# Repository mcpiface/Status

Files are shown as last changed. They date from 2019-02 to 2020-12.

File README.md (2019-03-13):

# McPiFace Status Board

Rack Mountable Raspberry Pi Status Board.

A status board in the McPiFace series, intended to fit the 19" rack frame as a quick status indicator.

Based on the Status Board Hat: https://thepihut.com/products/status-board-pro

## Versions

Version 2: Uses MCP23017 with The Pi's I2C. Uses the McPi I2C 6 Pin JST SH connection
https://github.com/mcpiface/Status/tree/master/V2

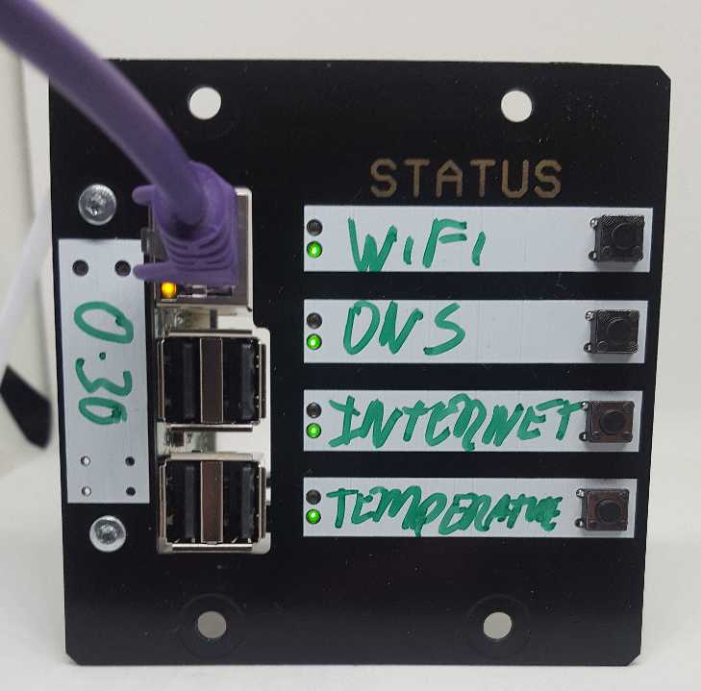
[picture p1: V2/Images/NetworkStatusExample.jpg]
V2 Status Board


Version 1: Needs 3x connectors and 15 GPIO on Pi. Uses Pi GPIOs - similar (different pins) to the Status Board Hat.
https://github.com/mcpiface/Status/tree/master/V1

## Sled

To mount the raspberry Pi a 3D printable sled is available:

https://www.thingiverse.com/thing:3488157

## Rack Mount Frame

DAP Audio 2 HE Rackblende f. Modulsystem 10 Segmente MP-1 from Music Store.

* UK: https://www.dv247.com/en_GB/GBP/DAP-Audio-2-HE-Rackblende-f-Modulsystem-10-Segmente-MP-1/art-PAH0017160-000

* Germany: https://www.musicstore.de/en_US/USD/DAP-Audio-2-HE-Rackblende-f-Modulsystem-10-Segmente-MP-1/art-PAH0017160-000

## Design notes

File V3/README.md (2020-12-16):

# McPiFace Status Board - Version 2

Rack Mountable Raspberry Pi Status Board.

Features 4x status indicators with red/green LEDs and optional buttons.

A status board in the McPiFace series, intended to fit the 19" rack frame as a quick status indicator.

This version uses the MCP23017 with The Pi's I2C. 

The connection uses the McPi I2C 6 Pin JST SH connection (1:1 connection with the first 6 pins of the Raspberry Pi second row of pins on the 40 pin header).

Status Board Usage

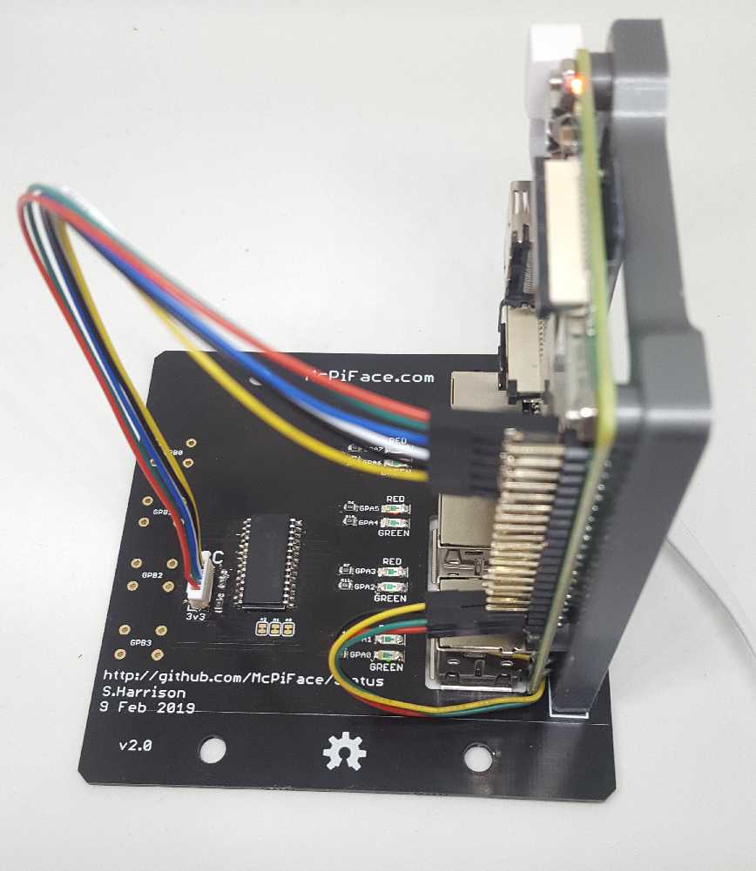
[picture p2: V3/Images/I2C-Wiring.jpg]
I2C Wiring


I2C Wiring 2

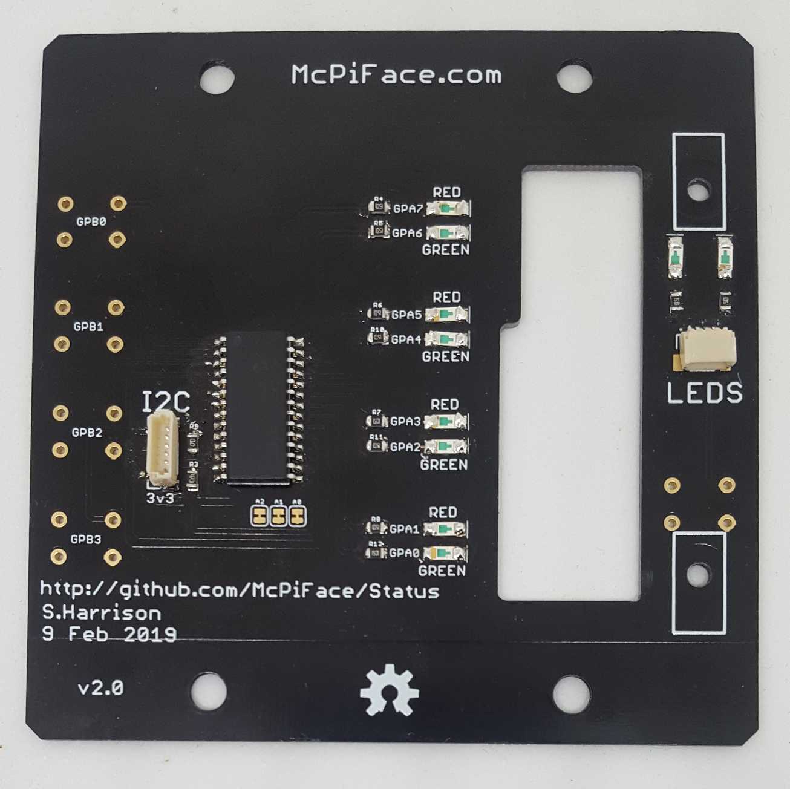
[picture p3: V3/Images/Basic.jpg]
Basic Layout


![Schematic] (Images/Schematic.png)

## Examples

See the examples folder for examples of use.

## Sled

To mount the raspberry Pi a 3D printable sled is available:

https://www.thingiverse.com/thing:3488157

## Rack Mount Frame

DAP Audio 2 HE Rackblende f. Modulsystem 10 Segmente MP-1 from Music Store.

* UK: https://www.dv247.com/en_GB/GBP/DAP-Audio-2-HE-Rackblende-f-Modulsystem-10-Segmente-MP-1/art-PAH0017160-000

* Germany: https://www.musicstore.de/en_US/USD/DAP-Audio-2-HE-Rackblende-f-Modulsystem-10-Segmente-MP-1/art-PAH0017160-000

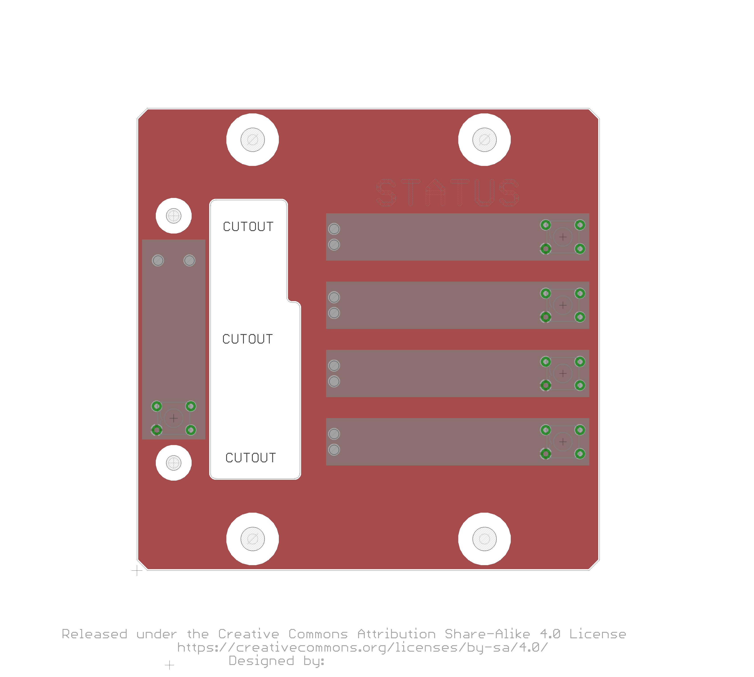
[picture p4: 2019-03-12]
V3/Images/PcbTopDesign.png

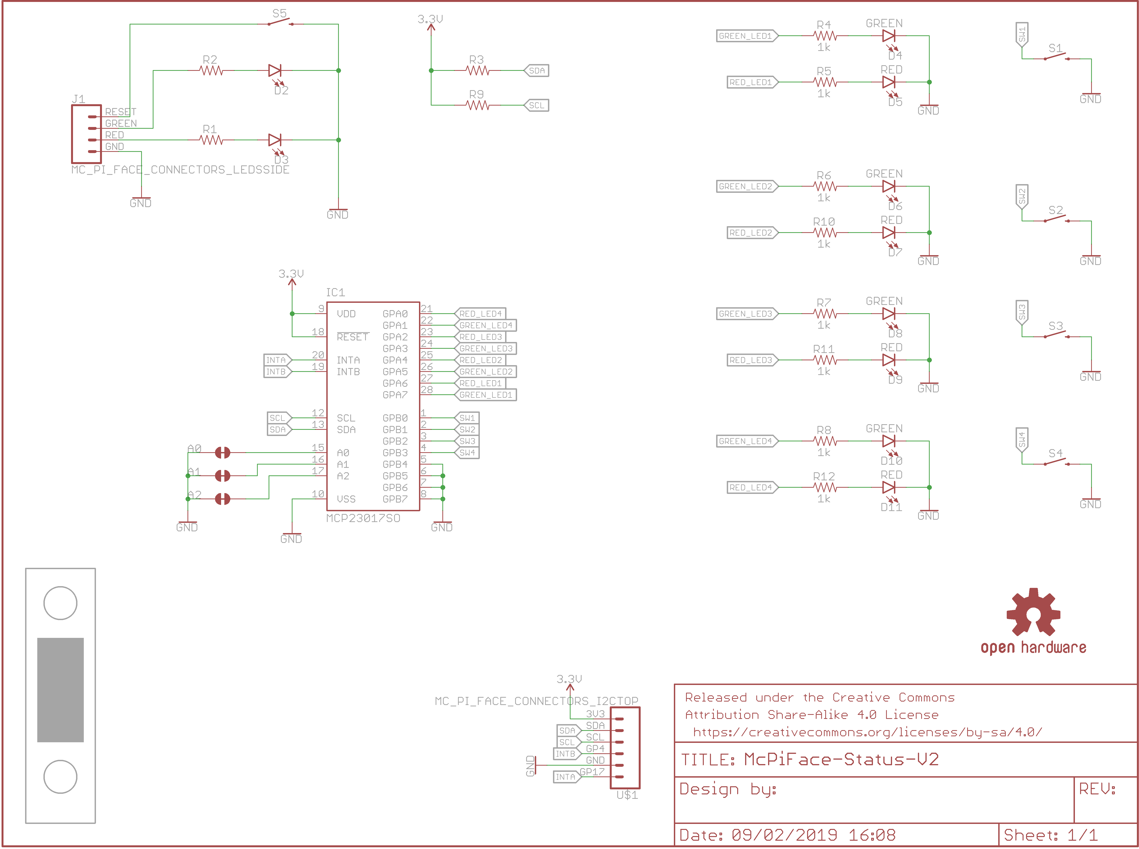
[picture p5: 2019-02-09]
V3/Images/Schematic.png

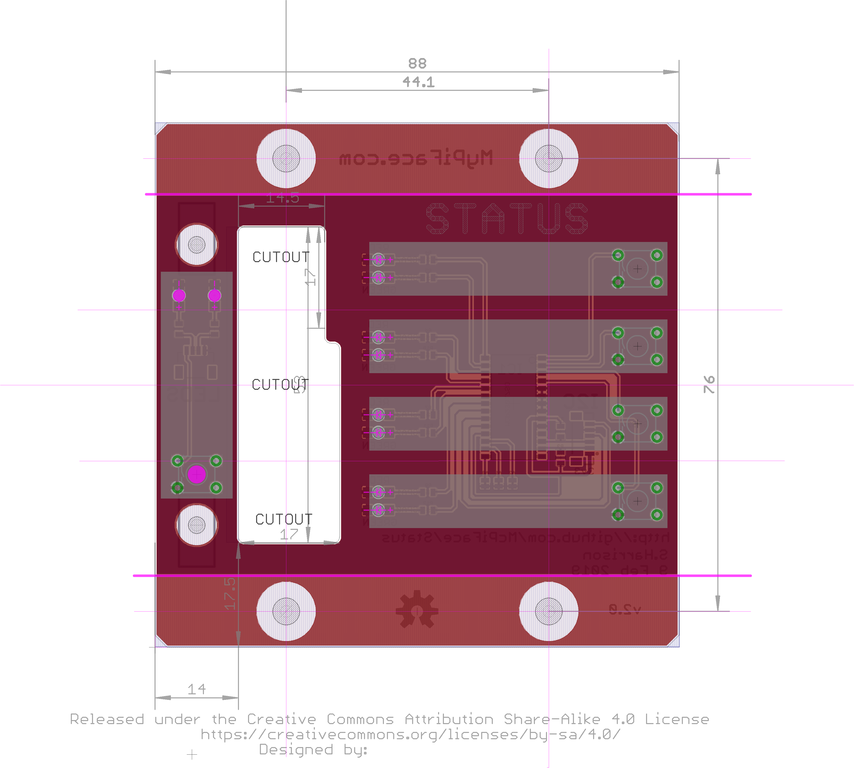
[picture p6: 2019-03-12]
V3/Images/PcbAllLayersDesign.png

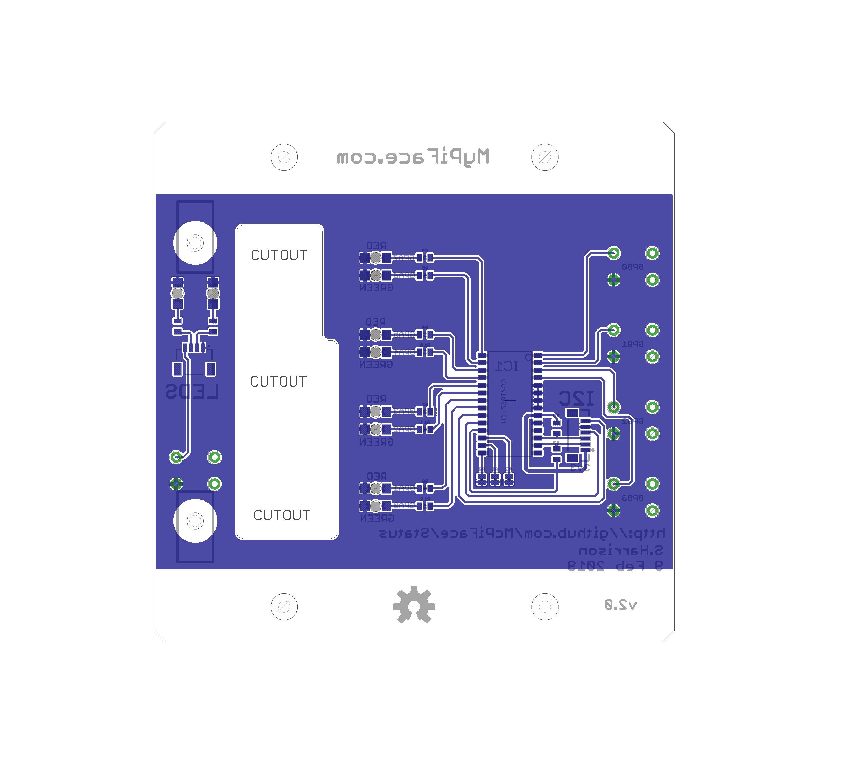
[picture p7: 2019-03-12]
V3/Images/PcbBottomDesign.png

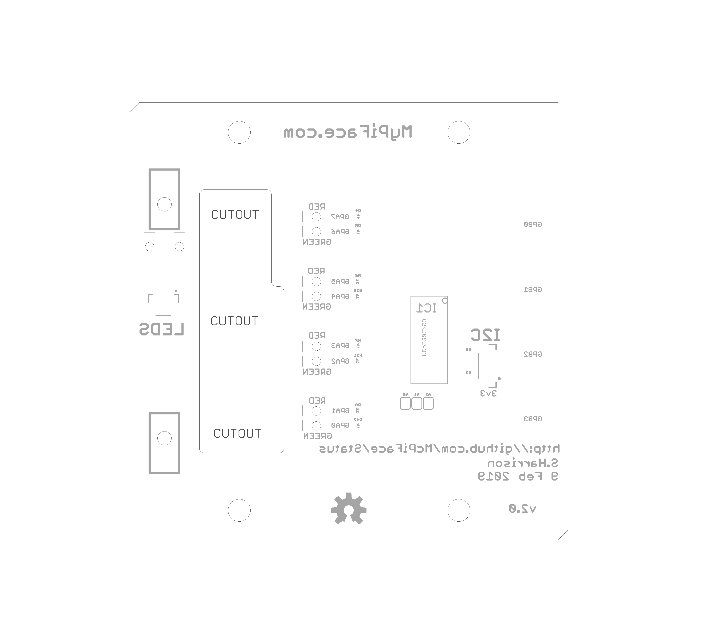
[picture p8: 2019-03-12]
V3/Images/PcbBottomSilkAndValues.png

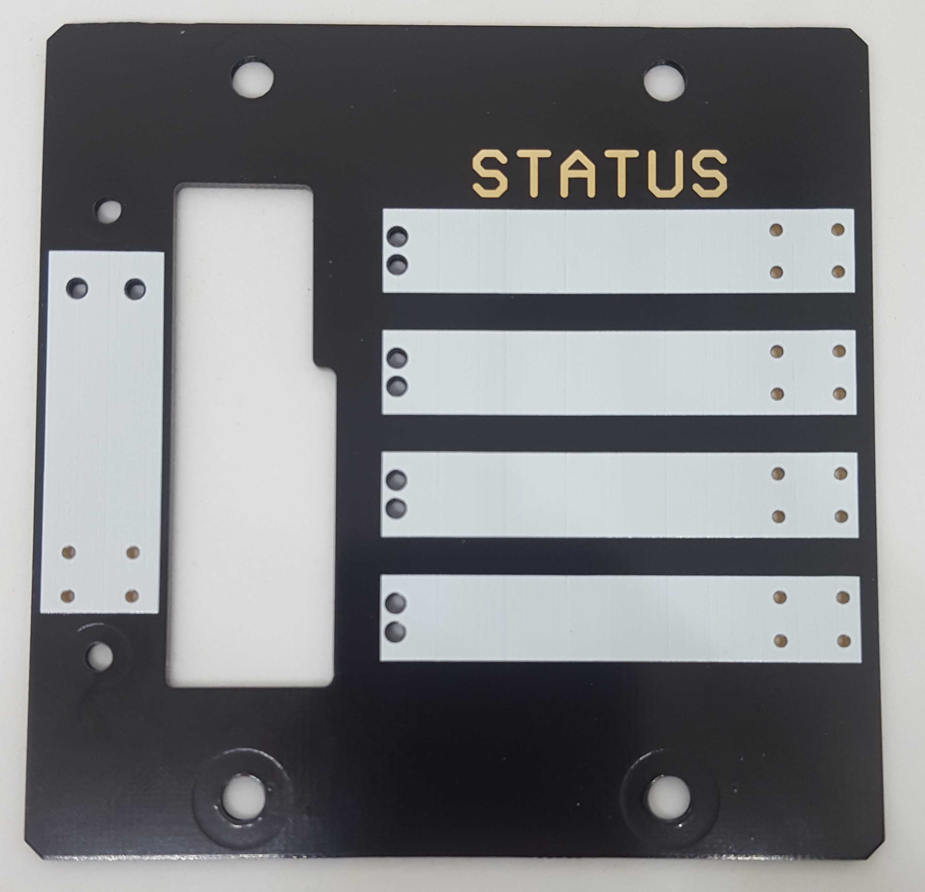
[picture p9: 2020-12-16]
V3/Images/PCBOnly.jpg

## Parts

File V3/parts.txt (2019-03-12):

Partlist

Exported from McPiFace-Status-V2.brd at 16/02/2019 17:04

EAGLE Version 7.4.0 Copyright (c) 1988-2015 CadSoft

Assembly variant: 

Part     Value                                                        Package                                Library            Position (mm)         Orientation

A0       JUMPER-SMT_2_NC_TRACE_SILK                                   SMT-JUMPER_2_NC_TRACE_SILK             SparkFun-Jumpers   (55.4 27.5)           MR90
A1       JUMPER-SMT_2_NC_TRACE_SILK                                   SMT-JUMPER_2_NC_TRACE_SILK             SparkFun-Jumpers   (57.7 27.5)           MR90
A2       JUMPER-SMT_2_NC_TRACE_SILK                                   SMT-JUMPER_2_NC_TRACE_SILK             SparkFun-Jumpers   (60 27.5)             MR90
D2                                                                    LED-1206-BOTTOM-2.0MM                  ThingySticks       (4 59)                MR90
D3                                                                    LED-1206-BOTTOM-2.0MM                  ThingySticks       (10 59)               MR90
D4       GREEN                                                        LED-1206-BOTTOM-2.0MM                  ThingySticks       (37.5 65)             MR0
D5       RED                                                          LED-1206-BOTTOM-2.0MM                  ThingySticks       (37.5 62)             MR0
D6       GREEN                                                        LED-1206-BOTTOM-2.0MM                  ThingySticks       (37.5 52)             MR0
D7       RED                                                          LED-1206-BOTTOM-2.0MM                  ThingySticks       (37.5 49)             MR0
D8       GREEN                                                        LED-1206-BOTTOM-2.0MM                  ThingySticks       (37.5 39)             MR0
D9       RED                                                          LED-1206-BOTTOM-2.0MM                  ThingySticks       (37.5 36)             MR0
D10      GREEN                                                        LED-1206-BOTTOM-2.0MM                  ThingySticks       (37.5 26)             MR0
D11      RED                                                          LED-1206-BOTTOM-2.0MM                  ThingySticks       (37.5 23)             MR0
IC1      MCP23017SO                                                   SO28W                                  McPiFace           (60.2 40.9)           MR270
J1       MC_PI_FACE_CONNECTORS_LEDSSIDE                               JST-4-SH-1.0MM-SIDE                    McPiFace           (6.8 49.8)            MR0
R1                                                                    0805                                   SparkFun-Resistors (10 53.4)             MR90
R2                                                                    0805                                   SparkFun-Resistors (4 53.4)              MR90
R3                                                                    0805                                   SparkFun-Resistors (68.1 31.8)           MR90
R4       1k                                                           0805                                   SparkFun-Resistors (45.8 65)             MR0
R5       1k                                                           0805                                   SparkFun-Resistors (45.8 62)             MR0
R6       1k                                                           0805                                   SparkFun-Resistors (45.8 52)             MR0
R7       1k                                                           0805                                   SparkFun-Resistors (45.8 39)             MR0
R8       1k                                                           0805                                   SparkFun-Resistors (45.8 26)             MR0
R9                                                                    0805                                   SparkFun-Resistors (68.1 36.2)           MR270
R10      1k                                                           0805                                   SparkFun-Resistors (45.8 49)             MR0
R11      1k                                                           0805                                   SparkFun-Resistors (45.8 36)             MR0
R12      1k                                                           0805                                   SparkFun-Resistors (45.8 23)             MR0
S1       MOMENTARY-SWITCH-SPSTTACKTILE_SWITCH_PTH_6.0MM_NO_TOP_RESIST TACTILE_SWITCH_PTH_6.0MM_NO_TOP_RESIST ThingySticks       (81 63.5)             R0
S2       MOMENTARY-SWITCH-SPSTTACKTILE_SWITCH_PTH_6.0MM_NO_TOP_RESIST TACTILE_SWITCH_PTH_6.0MM_NO_TOP_RESIST ThingySticks       (81 50.5)             R0
S3       MOMENTARY-SWITCH-SPSTTACKTILE_SWITCH_PTH_6.0MM_NO_TOP_RESIST TACTILE_SWITCH_PTH_6.0MM_NO_TOP_RESIST ThingySticks       (81 37.5)             R0
S4       MOMENTARY-SWITCH-SPSTTACKTILE_SWITCH_PTH_6.0MM_NO_TOP_RESIST TACTILE_SWITCH_PTH_6.0MM_NO_TOP_RESIST ThingySticks       (81 24.5)             R0
S5       MOMENTARY-SWITCH-SPSTTACKTILE_SWITCH_PTH_6.0MM_NO_TOP_RESIST TACTILE_SWITCH_PTH_6.0MM_NO_TOP_RESIST ThingySticks       (7 29)                R0
U$1      MC_PI_FACE_CONNECTORS_I2CTOP                                 JST-6-SH-1.0MM-TOP                     McPiFace           (71.7 35)             MR90

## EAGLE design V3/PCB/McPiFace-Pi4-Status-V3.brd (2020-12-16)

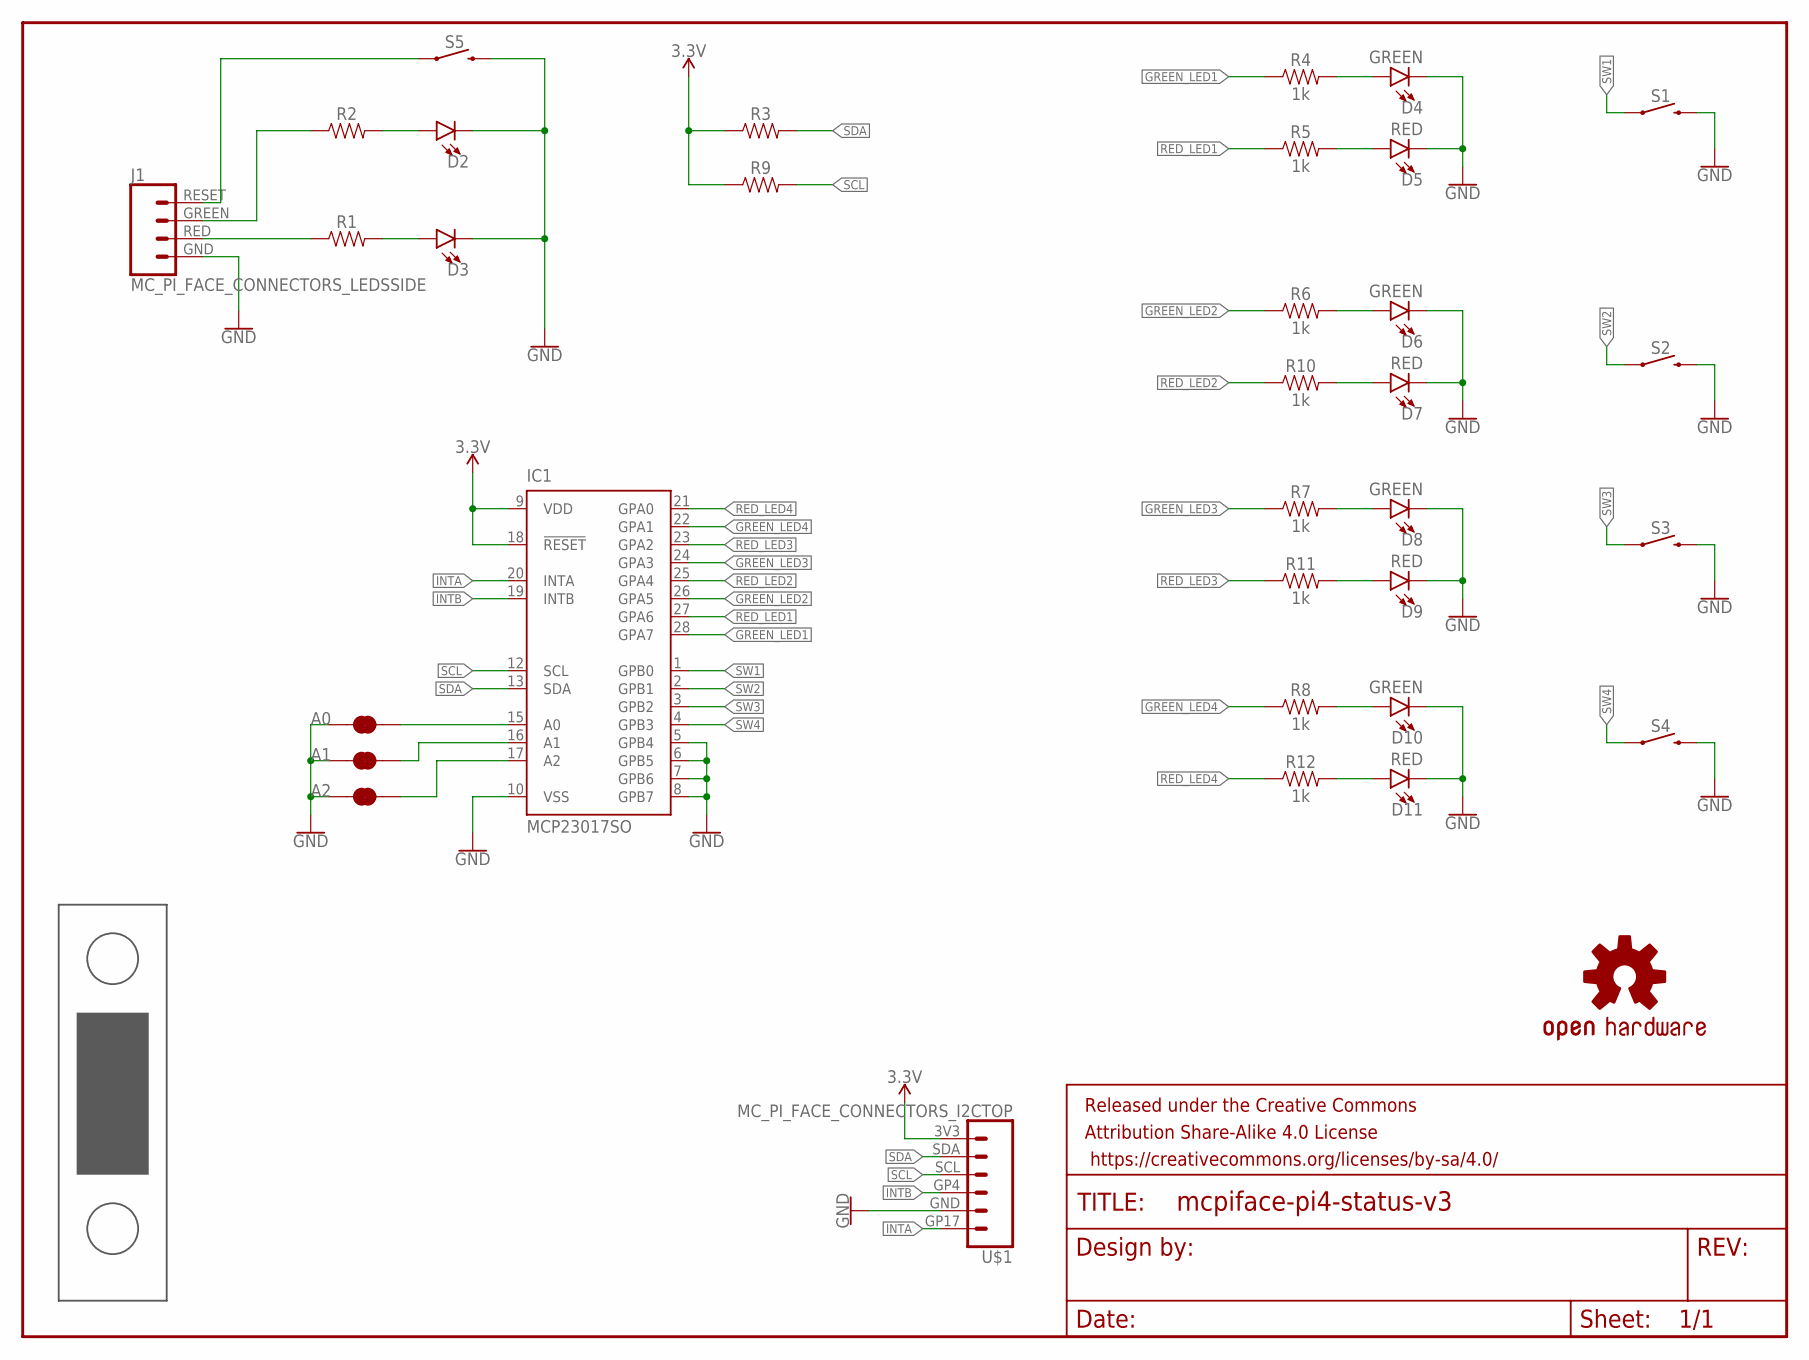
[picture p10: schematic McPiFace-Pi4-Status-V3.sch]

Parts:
A0, A1, A2: JUMPER-SMT_2_NC_TRACE_SILK; SMT-JUMPER_2_NC_TRACE_SILK
D2: LEDLED-1206-BOTTOM-2.0MM-GREEN; LED-1206-BOTTOM-2.0MM
D3: LEDLED-1206-BOTTOM-2.0MM-RED; LED-1206-BOTTOM-2.0MM
D4, D6, D8, D10: GREEN; LED-1206-BOTTOM-2.0MM
D5, D7, D9, D11: RED; LED-1206-BOTTOM-2.0MM
FP1: MC_PI_4_FACE_PANELDOUBLE; MC_PI_4-DOUBLE_FACE
FRAME1: FRAME-LETTER; CREATIVE_COMMONS
IC1: MCP23017SO; SO28W
J1: MC_PI_FACE_CONNECTORS_LEDSSIDE; JST-4-SH-1.0MM-SIDE
LOGO1: OSHW-LOGOL; OSHW-LOGO-L
R1, R2, R3, R9: 0805
R4, R5, R6, R7, R8, R10, R11, R12: 1k; 0805
S1, S5: MOMENTARY-SWITCH-SPSTTACKTILE_SWITCH_PTH_6.0MM_NO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; TACTILE_SWITCH_PTH_6.0MM_NO_TOP_RESIST; FARNELL 2435162
S2, S3, S4: MOMENTARY-SWITCH-SPSTTACKTILE_SWITCH_PTH_6.0MM_NO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; TACTILE_SWITCH_PTH_6.0MM_NO_TOP_RESIST
U$1: MC_PI_FACE_CONNECTORS_I2CTOP; JST-6-SH-1.0MM-TOP

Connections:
3.3V: IC1.9 (VDD), IC1.18 (!RESET), R3.1, R9.1, U$1.3V3
GND: A0.1, A1.1, A2.1, D2.C, D3.C, D4.C, D5.C, D6.C, D7.C, D8.C, D9.C, D10.C, D11.C, IC1.5 (GPB4), IC1.6 (GPB5), IC1.7 (GPB6), IC1.8 (GPB7), IC1.10 (VSS), J1.GND, S1.3 (2), S2.3 (2), S3.3 (2), S4.3 (2), S5.3 (2), U$1.GND
GREEN_LED1: IC1.28 (GPA7), R4.1
GREEN_LED2: IC1.26 (GPA5), R6.1
GREEN_LED3: IC1.24 (GPA3), R7.1
GREEN_LED4: IC1.22 (GPA1), R8.1
INTA: IC1.20 (INTA), U$1.GP17
INTB: IC1.19 (INTB), U$1.GP4
unnamed: D4.A, R4.2
unnamed: J1.RESET, S5.1
unnamed: D2.A, R2.2
unnamed: D3.A, R1.2
unnamed: J1.RED, R1.1
unnamed: J1.GREEN, R2.1
unnamed: D6.A, R6.2
unnamed: D10.A, R8.2
unnamed: D8.A, R7.2
unnamed: D5.A, R5.2
unnamed: D7.A, R10.2
unnamed: D9.A, R11.2
unnamed: D11.A, R12.2
unnamed: A0.2, IC1.15 (A0)
unnamed: A1.2, IC1.16 (A1)
unnamed: A2.2, IC1.17 (A2)
RED_LED1: IC1.27 (GPA6), R5.1
RED_LED2: IC1.25 (GPA4), R10.1
RED_LED3: IC1.23 (GPA2), R11.1
RED_LED4: IC1.21 (GPA0), R12.1
SCL: IC1.12 (SCL), R9.2, U$1.SCL
SDA: IC1.13 (SDA), R3.2, U$1.SDA
SW1: IC1.1 (GPB0), S1.1
SW2: IC1.2 (GPB1), S2.1
SW3: IC1.3 (GPB2), S3.1
SW4: IC1.4 (GPB3), S4.1

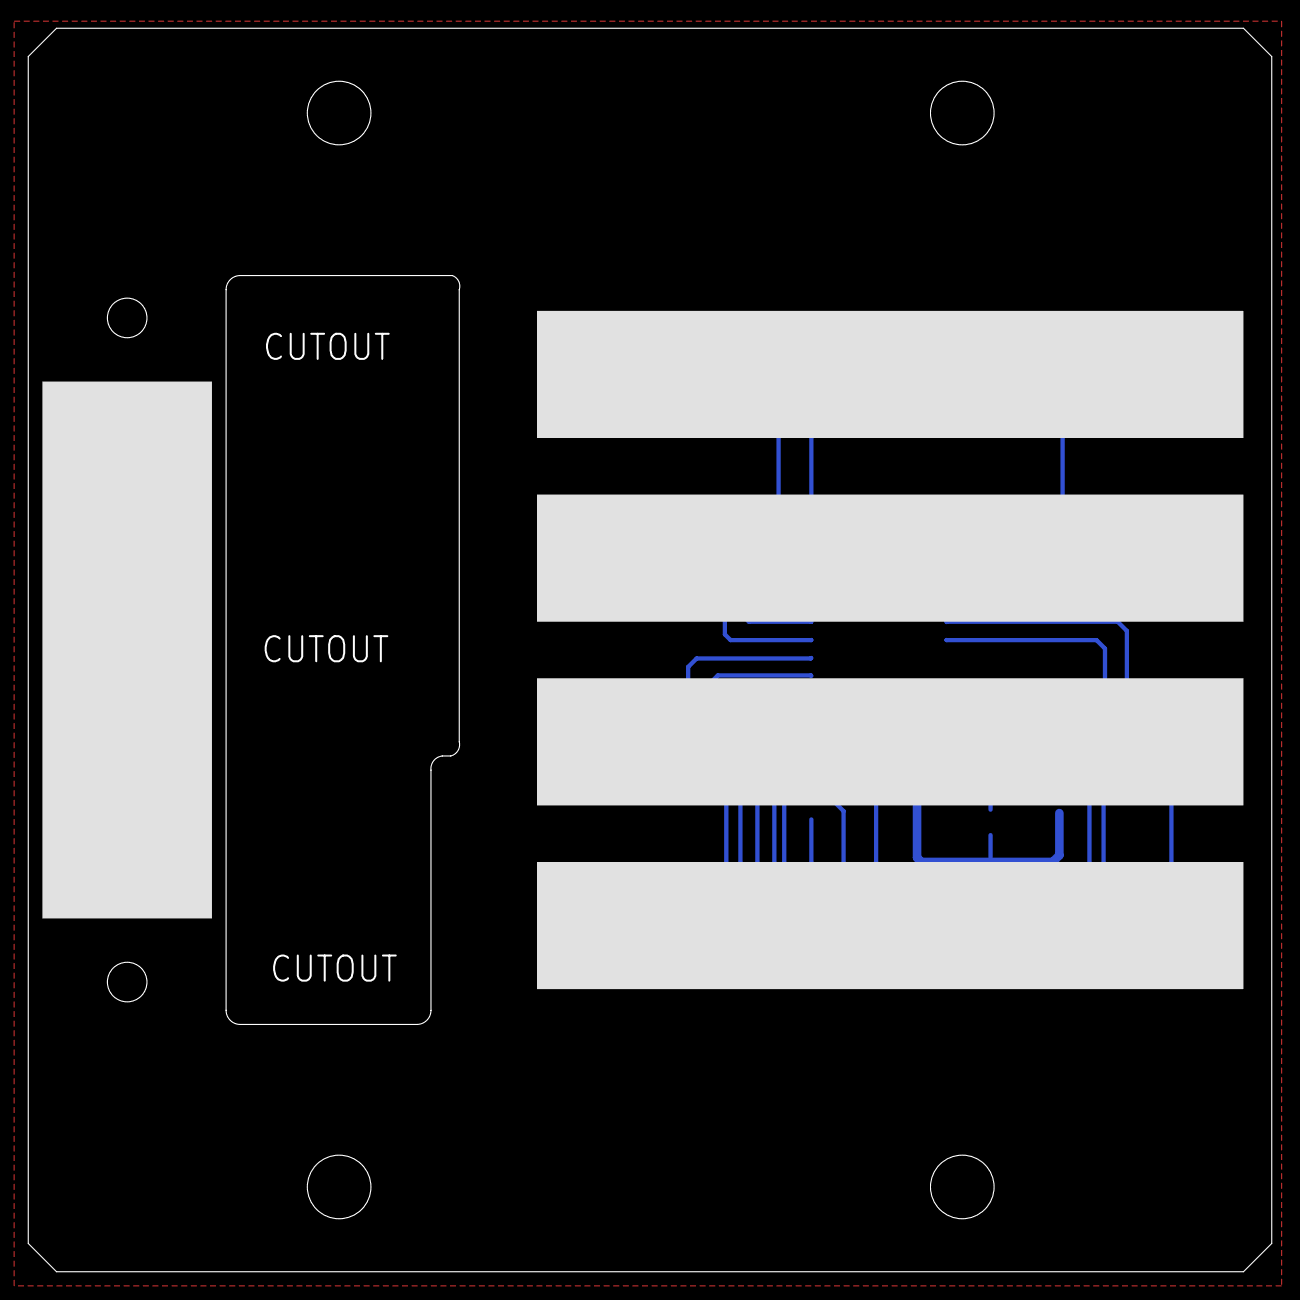
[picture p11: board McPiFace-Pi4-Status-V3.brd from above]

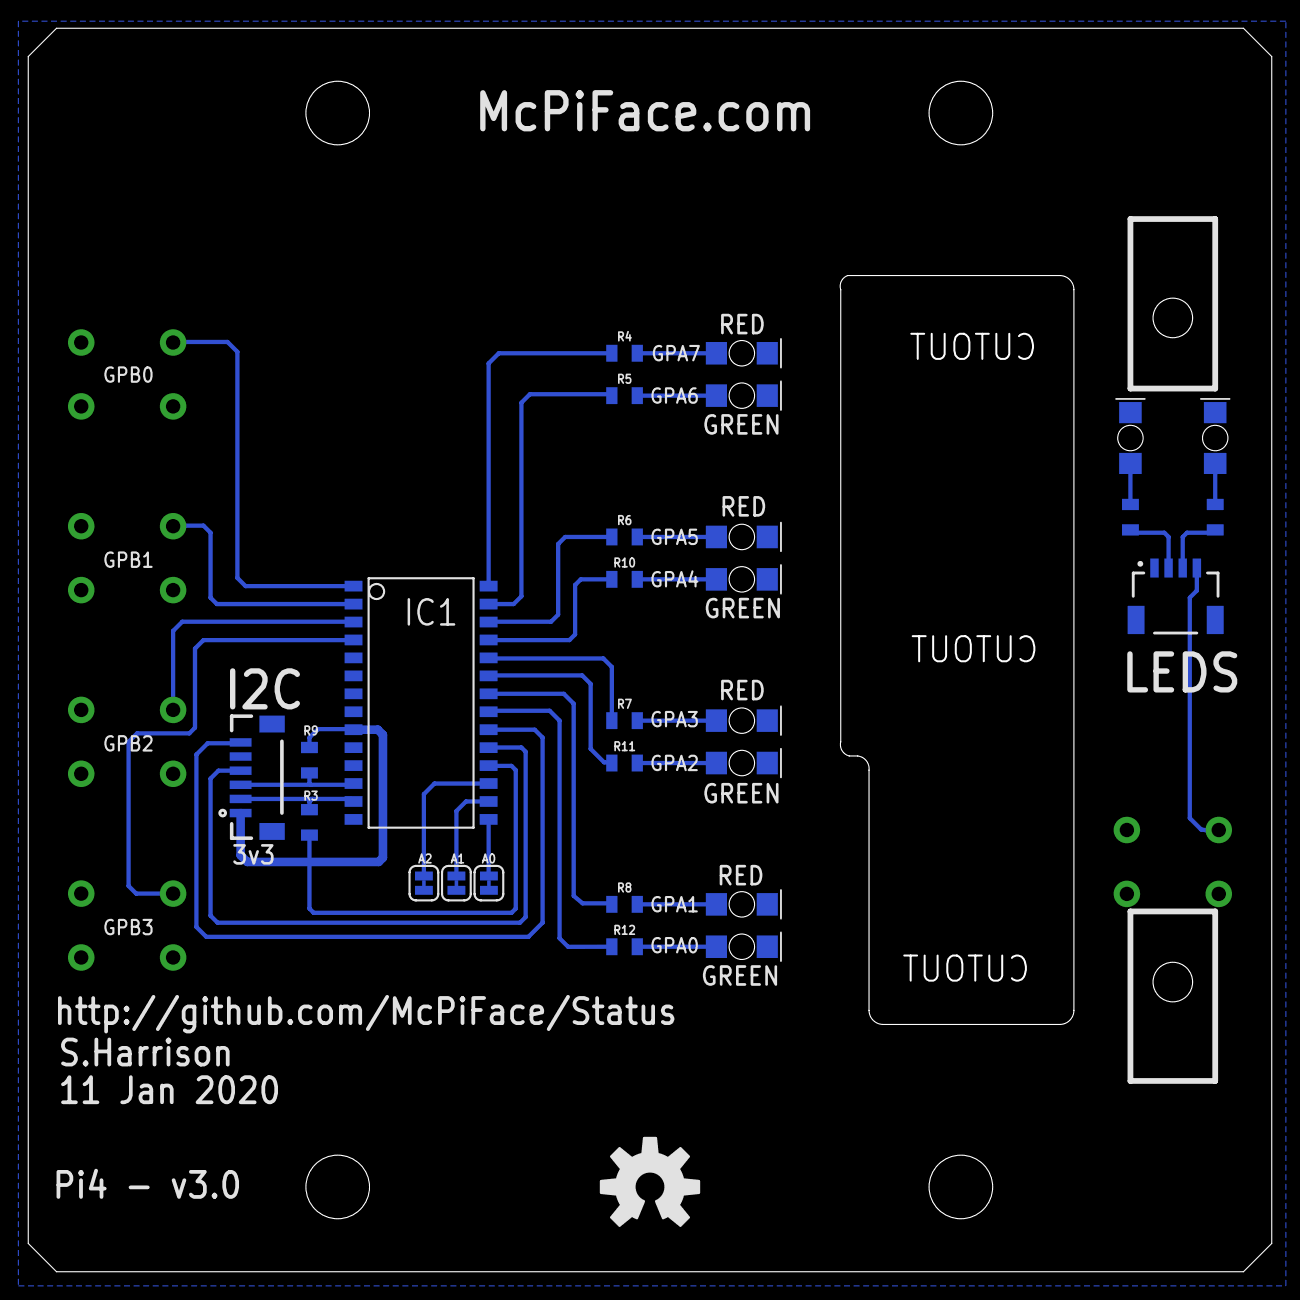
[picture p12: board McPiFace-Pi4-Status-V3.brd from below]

Board: 2 copper layers, 88.0 x 88.0 mm, 36 parts (29 on the bottom side), 34 nets.

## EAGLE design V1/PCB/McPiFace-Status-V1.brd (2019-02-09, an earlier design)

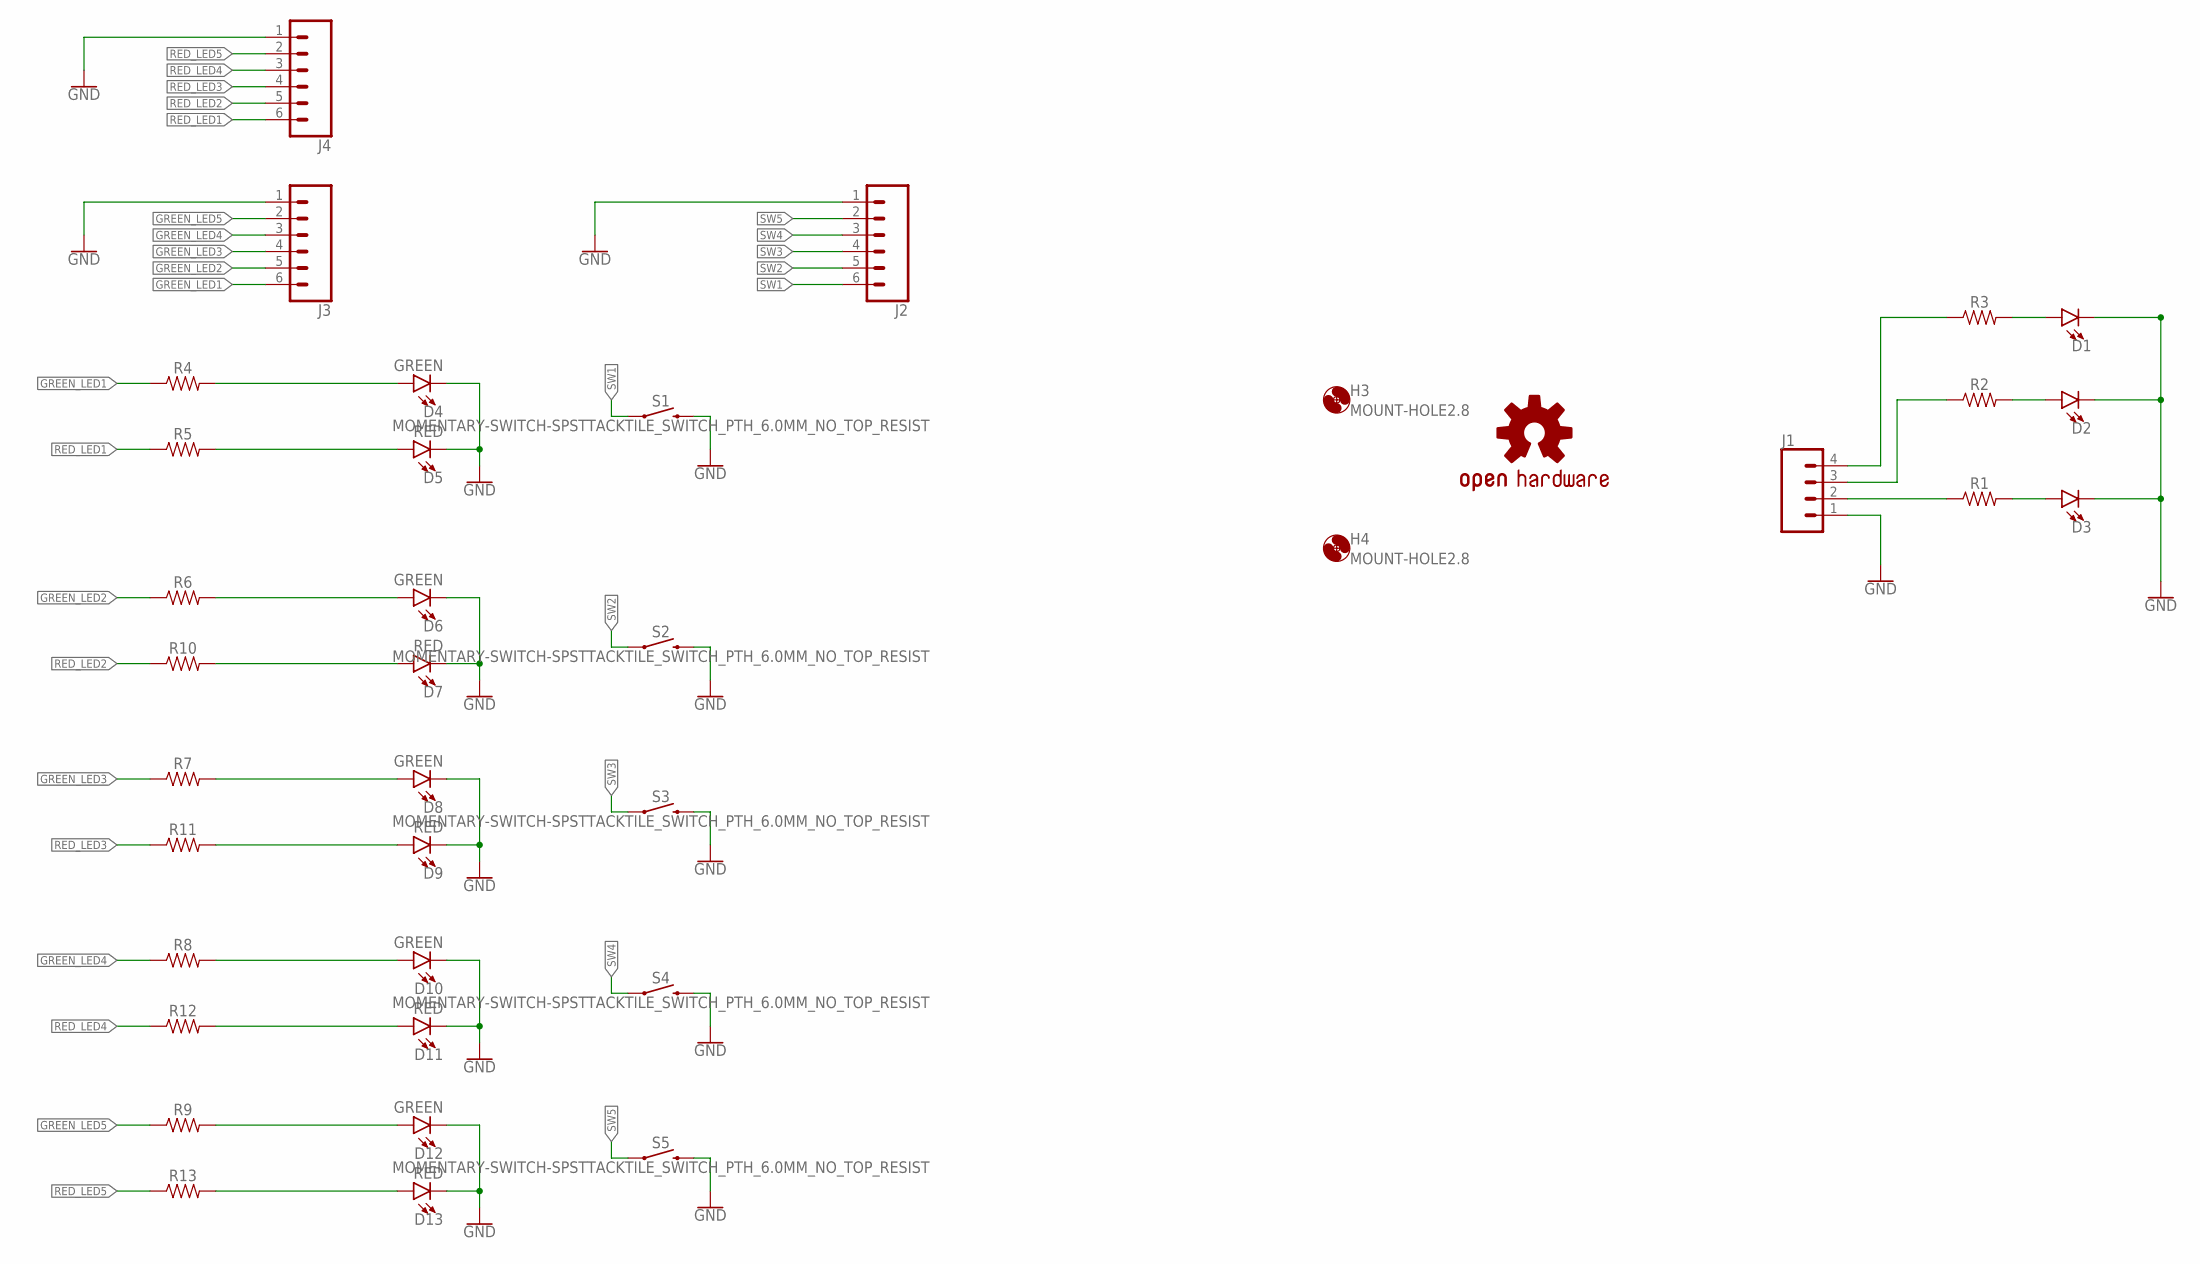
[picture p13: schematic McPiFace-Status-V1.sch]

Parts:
D1, D2, D3: LED1206-BOTTOM-1.6MM; LED-1206-BOTTOM-1.6MM
D4, D6, D8, D10, D12: GREEN; LED-1206
D5, D7, D9, D11, D13: RED; LED-1206
H3, H4: MOUNT-HOLE2.8; 2,8
J1: CONN_04SMD2; 1X04_1MM_RA
J2, J3, J4: CONN_06SMD-1MM; 1X06-1MM
LOGO1: OSHW-LOGOL; OSHW-LOGO-L
R1, R2, R3: 1206
R4, R5, R6, R7, R8, R9, R10, R11, R12, R13: 0805
S1: MOMENTARY-SWITCH-SPSTTACKTILE_SWITCH_PTH_6.0MM_NO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; TACTILE_SWITCH_PTH_6.0MM_NO_TOP_RESIST; FARNELL 2435162
S2, S3, S4, S5: MOMENTARY-SWITCH-SPSTTACKTILE_SWITCH_PTH_6.0MM_NO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; TACTILE_SWITCH_PTH_6.0MM_NO_TOP_RESIST

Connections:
GND: D1.C, D2.C, D3.C, D4.C, D5.C, D6.C, D7.C, D8.C, D9.C, D10.C, D11.C, D12.C, D13.C, J1.1, J2.1, J3.1, J4.1, S1.3 (2), S2.3 (2), S3.3 (2), S4.3 (2), S5.3 (2)
GREEN_LED1: J3.6, R4.1
GREEN_LED2: J3.5, R6.1
GREEN_LED3: J3.4, R7.1
GREEN_LED4: J3.3, R8.1
GREEN_LED5: J3.2, R9.1
unnamed: D4.A, R4.2
unnamed: D1.A, R3.2
unnamed: D2.A, R2.2
unnamed: D3.A, R1.2
unnamed: J1.2, R1.1
unnamed: J1.3, R2.1
unnamed: J1.4, R3.1
unnamed: D6.A, R6.2
unnamed: D12.A, R9.2
unnamed: D10.A, R8.2
unnamed: D8.A, R7.2
unnamed: D5.A, R5.2
unnamed: D7.A, R10.2
unnamed: D9.A, R11.2
unnamed: D11.A, R12.2
unnamed: D13.A, R13.2
RED_LED1: J4.6, R5.1
RED_LED2: J4.5, R10.1
RED_LED3: J4.4, R11.1
RED_LED4: J4.3, R12.1
RED_LED5: J4.2, R13.1
SW1: J2.6, S1.1
SW2: J2.5, S2.1
SW3: J2.4, S3.1
SW4: J2.3, S4.1
SW5: J2.2, S5.1

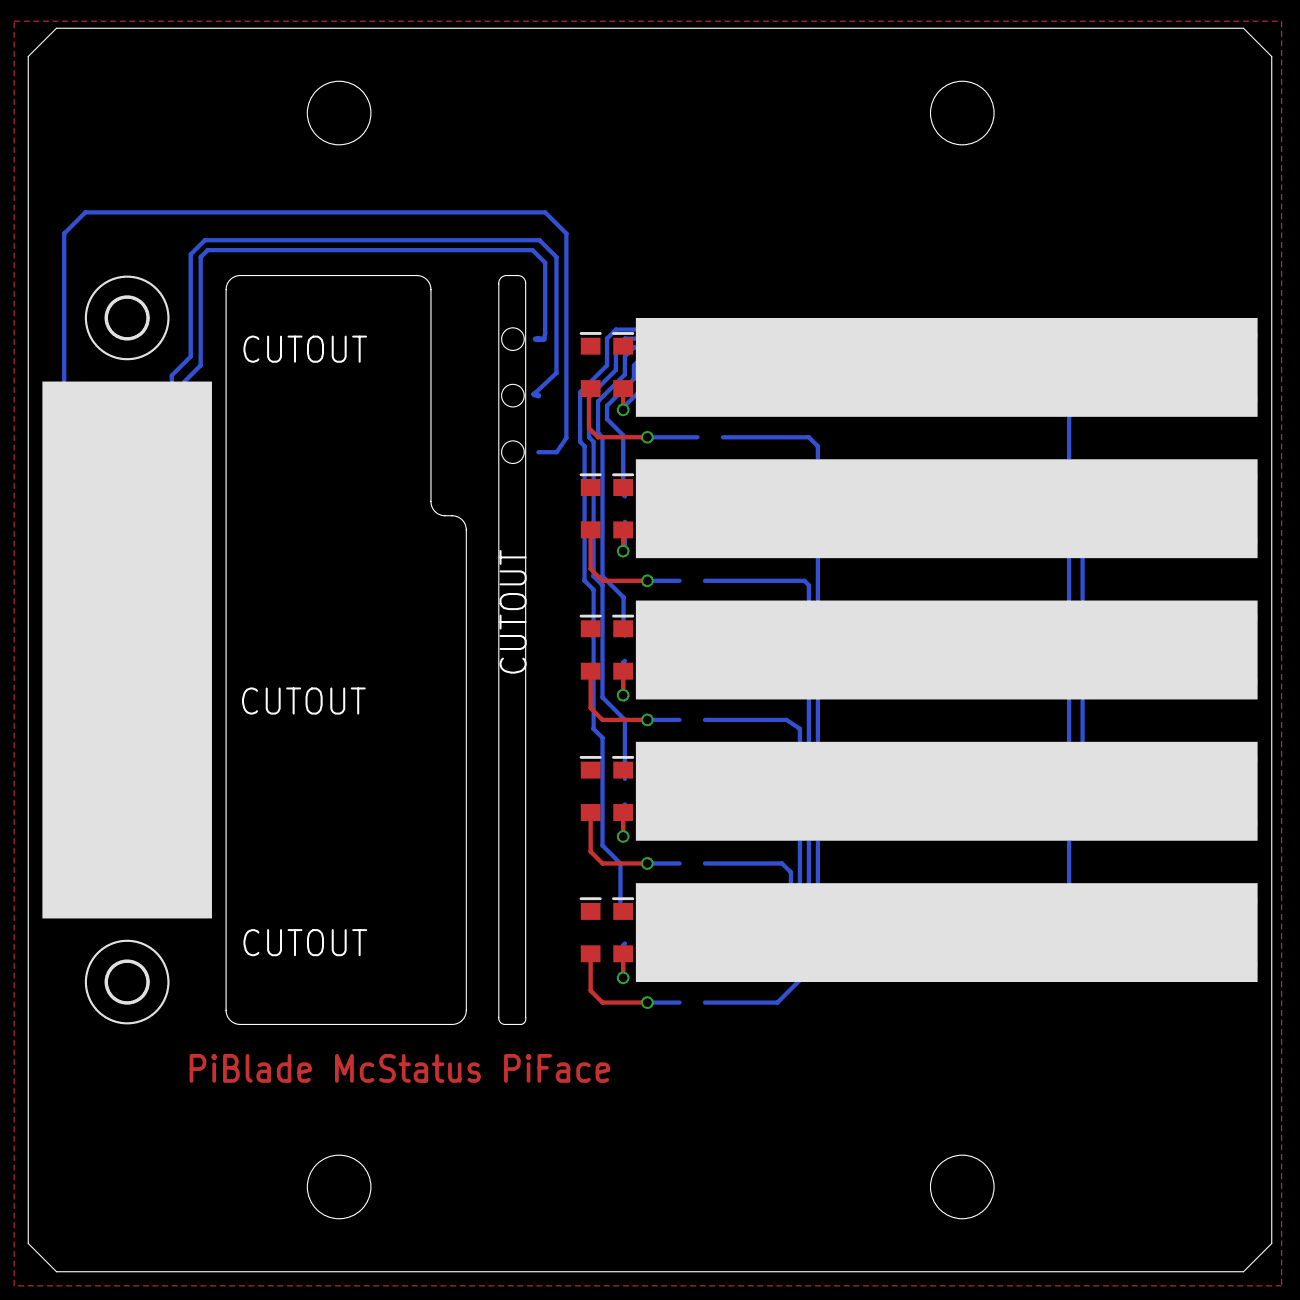
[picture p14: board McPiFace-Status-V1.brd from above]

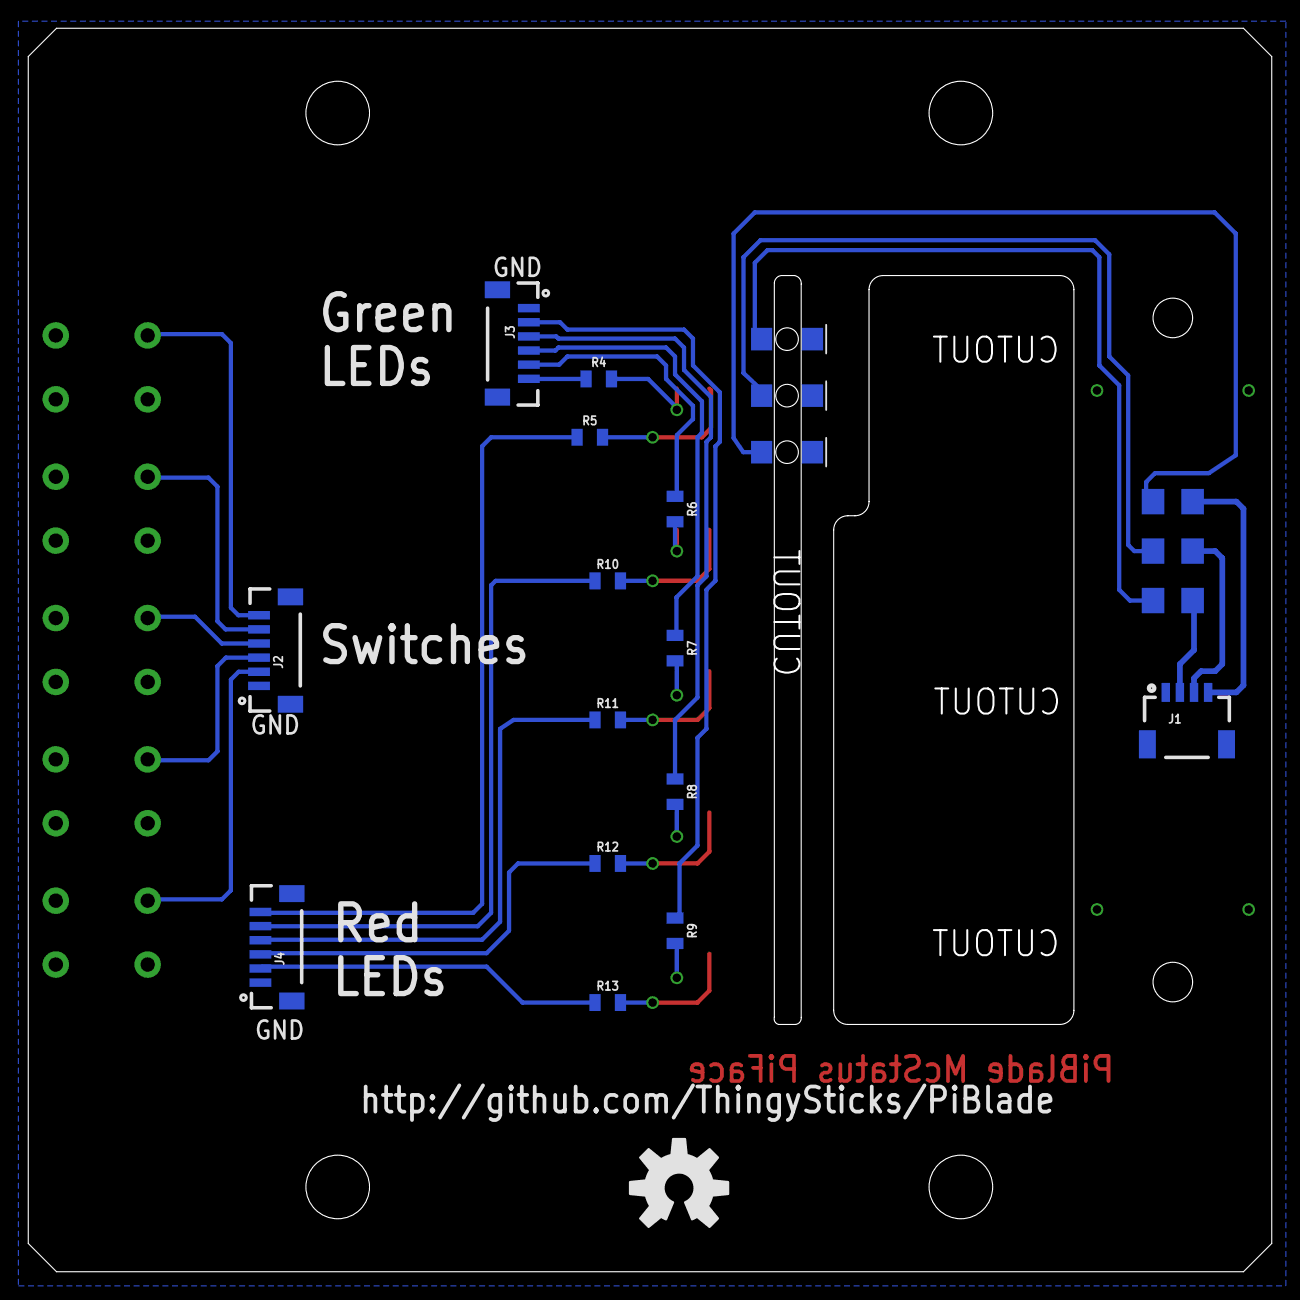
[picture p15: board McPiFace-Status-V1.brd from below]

Board: 2 copper layers, 88.0 x 88.0 mm, 38 parts (21 on the bottom side), 32 nets.

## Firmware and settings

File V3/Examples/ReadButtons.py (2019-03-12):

import smbus
import time
 
# Use I2C Bus 1
bus = smbus.SMBus(1)

# MCP23017 Data Sheet: http://ww1.microchip.com/downloads/en/devicedoc/20001952c.pdf

# Example derived from:
# https://www.raspberrypi-spy.co.uk/2013/07/how-to-use-a-mcp23017-i2c-port-expander-with-the-raspberry-pi-part-2/

# Addresses with IOCON.BANK = 0 (default)
DEVICE = 0x20 # Device address (A0-A2)
IODIRA = 0x00 # Pin direction register
IODIRB = 0x01 # Port B direction register
GPIOA  = 0x12 # Register for LEDs
GPIOB  = 0x13 # Register for Buttons
IOCONA = 0x0A # Bank A IOCON CONFIGURATION REGISTER
IOCONB = 0x0B
GPPUA  = 0x0C # Bank A GPIO Pullups.
GPPUB  = 0x0D
INTFA  = 0x0E # Bank A Interrupt flats.
INTFB  = 0x0F
OLATA  = 0x14 # Bank A output latch
OLATB  = 0x15

# Set all GPA pins as output.
bus.write_byte_data(DEVICE,IODIRA,0x00)
 
# Set all GPB pins as input.
# Only GPB0..4 are actually used.
bus.write_byte_data(DEVICE,IODIRB,0xFF)

# Configure GPB0..3 as pullup
bus.write_byte_data(DEVICE,GPPUB,0x0F)

# Interrupt config.
# ODR: 1 (Open-drain output (overrides the INTPOL bit.))
# INTPOL: 0 (Active-low)
bus.write_byte_data(DEVICE,IOCONB,0x04)

# Interrupt on GPB0..4
bus.write_byte_data(DEVICE,INTFB,0x0F)
 
# Loop until user presses CTRL-C
while True:
  # Set LEDs to Green
  bus.write_byte_data(DEVICE,OLATA,0x55)
 
  # Read state of GPIOB register
  button = bus.read_byte_data(DEVICE,GPIOB)
 
  # GPB0..3 should be high if not pressed.
  # active low on button press.
  # GPB4..7 are tied low.
  if button != 0x0F:
   print "Switch was pressed! %x" % button

   # Make all LEDs red to indicate a button press
   bus.write_byte_data(DEVICE,OLATA,0xAA)
   time.sleep(2)

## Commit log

2019-02-09 Copied V1 over from ThingySticks respository.
    Added V2 to use I2C interface with IO driver chip and 2 interrupt options.
    [McPiFace-Status-V1.brd, McPiFace-Status-V1.sch, McPiFace-Status-V2.brd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]
2019-03-12 Updated LEDs used to use the larger hole version.
    [McPiFace-Status-V2.brd, McPiFace-Status-V2.sch]
2020-12-16 Fix I2C wiring image.
2020-12-16 Added V3
    [McPiFace-Pi4-Status-V3.brd, McPiFace-Pi4-Status-V3.sch]

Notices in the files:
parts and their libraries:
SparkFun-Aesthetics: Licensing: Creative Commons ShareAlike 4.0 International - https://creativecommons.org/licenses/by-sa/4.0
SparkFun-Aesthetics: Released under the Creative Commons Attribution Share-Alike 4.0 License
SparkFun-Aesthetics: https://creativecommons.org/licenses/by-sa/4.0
